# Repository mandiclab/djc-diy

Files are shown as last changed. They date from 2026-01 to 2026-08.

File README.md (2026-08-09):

# *DJC-DIY - The World's First DIY DJ Controller*
DJC-DIY is an open-source DJ controller that you can make at home without special tools, skill or knowledge.  
It works with [Mixxx](https://mixxx.org/) (open-source DJ software).  

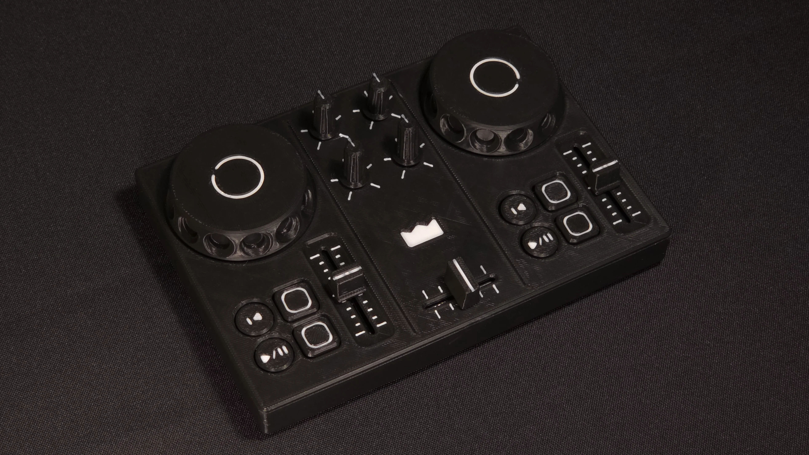
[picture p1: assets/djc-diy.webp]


## ▶️ Videos
👀 **[Preview](https://youtu.be/gbPC8Bg0U9I?si=byUlCWdjjWGdwAEo)**  
🎧 **[Demo](https://youtu.be/WDb8kAIuzXc)**  
🎓 **[Assemby Tutorial](https://youtu.be/Z4C7toXesU8?si=7H11E58jwsbux4Dv)**  
🎓 **[DJ Tutorial - *coming soon*]()**  

## 👥 Community
☕ Support by donating on **[Ko-fi](https://ko-fi.com/mandiclab)**.  
🚀 Join the community on **[Discord](https://discord.gg/aApBQxZUcu)**.  
📱 Subscribe on  **[YouTube](https://youtube.com/@mandiclab)** and follow on **[Instagram](https://instagram.com/mandiclab)**.

## 📁 Project Files

🧊 **3D Models** - *.stl (mesh files for 3D printing), .FCStd (FreeCad source files)*  
⚙️ **Firmware** - *here's the firmware*  
🎛️ **Mixxx Mapping Files** - *and here are the mapping files*

## ⬇️ Download

Download latest stable release from **[releases](https://github.com/mandiclab/djc-diy/releases)**. 

>[!WARNING]
>*If you download the whole repo, there's a chance that you'll download files in the middle of the update process and get incomplete version.*

## 🔩 Parts List

### 3D Printed Parts
| **🔢 Quantity** | **🧊 Part** | **📄 File Name** |
|:---:|:---|:---|
| x1 | Case | case.stl |
| x1 | Front Panel | front-panel.stl |
| x1 | Arduino Spring | arduino-spring.stl |
| x2 | Jog Wheel | jog-wheel.stl |
| x2 | Play/Pause | play-pause.stl |
| x2 | Cue | cue.stl |
| x4 | Performance Pad | performance-pad.stl |
| x1 | Crossfader | crossfader.stl |
| x2 | Tempo Fader | tempo-fader.stl |
| x4 | Knob | knob.stl |
| x4 | Feet | feet.stl |

### 📦 Order 3D Printed Parts From PCBWay 
Thanks to our sponsor **[PCBWay](https://www.pcbway.com/)**, you can now order all 3D printed parts and have them delivered to your door.  
Not having access to a 3D printer is no longer a problem.  

🛒 **[ORDER ALL 3D PRINTED PARTS](https://www.pcbway.com/rapid-prototyping/manufacture/?type=3&reffercode=Project&projectattid=78823)**  
🔎 **[SEE THE WHOLE PROJECT](https://www.pcbway.com/project/shareproject/DIY_DJ_Controller_DJC_DIY_adac65c3.html)**  

*By ordering through PCBWay, you’re also supporting the project and helping future development.*  

### Electronic Components  
| **🔢 Quantity** | **🧩 Component** | **📄 Description** |
|:---:|:---|:---|
| x1 | 🧠 Microcontroller | Arduino Pro Micro - ATmega32U4 - USB Type C |
| x8 | 🔘 Buttons | B3F-4055 - 12x12x7.3mm |
| x4 | 🎛️ Rotary Potentiometers | R0902N - B103 - 10kΩ - 23mm shaft lenght - D shaft |
| x3 | 🎚️ Slide Potentiometers | 60mm - B103 - 10kΩ - 15mm handle lenght |
| x2 | 🔄 Rotary Encoders | EC11 - 15mm shaft lenght - D shaft - without push button |
| x4 | ➖ Resistor | 1/4W - 10kΩ |
|  | 🔌 Wires | 24 AWG - Red, Black, Blue, Green, Yellow|

## 💻 Required Software
**Download and install required software**  

**Arduino IDE** - *an open-source development environment for programming Arduino boards* - **[DOWNLOAD](https://www.arduino.cc/en/software/)**  
**Mixxx** - *an open source DJ software* - **[DOWNLOAD](https://mixxx.org/download/)** 

## 🛠️ Assembly Guide

### 1. Acquire electronic components  
Acquire all electronic components from the electronic components list.  
I personally bought everything from Aliexpress and had no problems.

### 2. 3D print parts  
3D print all parts from the 3D printed parts list.  
I used max speed, 15% infill, .2mm layer height. Use support where needed.  
If something can't be pulled onto a part, try printing it at 105% scale.  

### 3. Wire electronics in the case  
Here you can see an illustrated schematic.  
Solder everything as shown.  

This is the layout of the electronic components.  
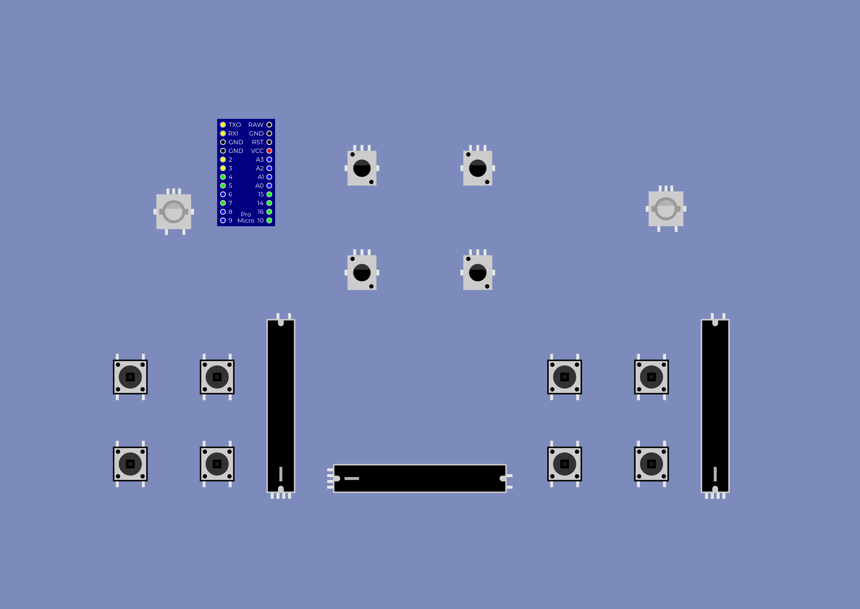
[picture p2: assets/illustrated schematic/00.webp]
  

First solder left rotary encoder.  
At the beginning, solder the pins from the bottom side of the Arduino.  
Use this opportunity to leave more space on the top side for later, because once several electronic components are soldered in place, the Arduino will no longer be movable, and soldering from the bottom side of the pins will no longer be possible.  
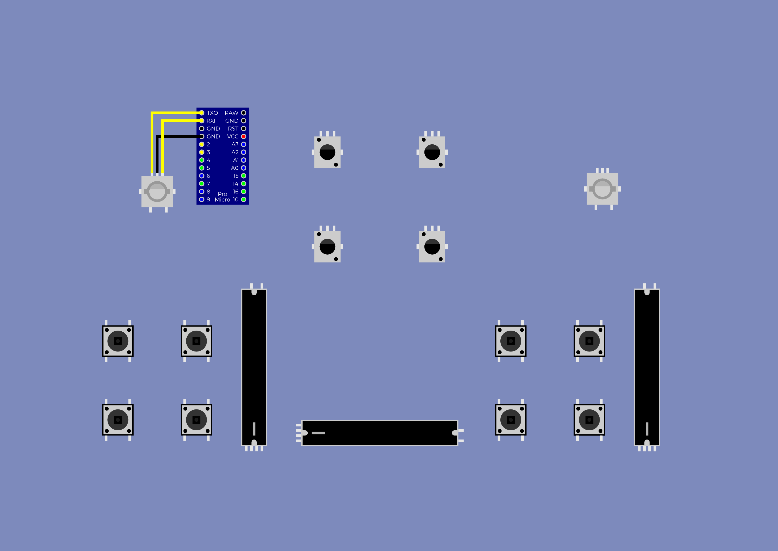
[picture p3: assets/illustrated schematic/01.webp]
  

Then solder right rotary encoder.  
Also solder the pins from the bottom side.  
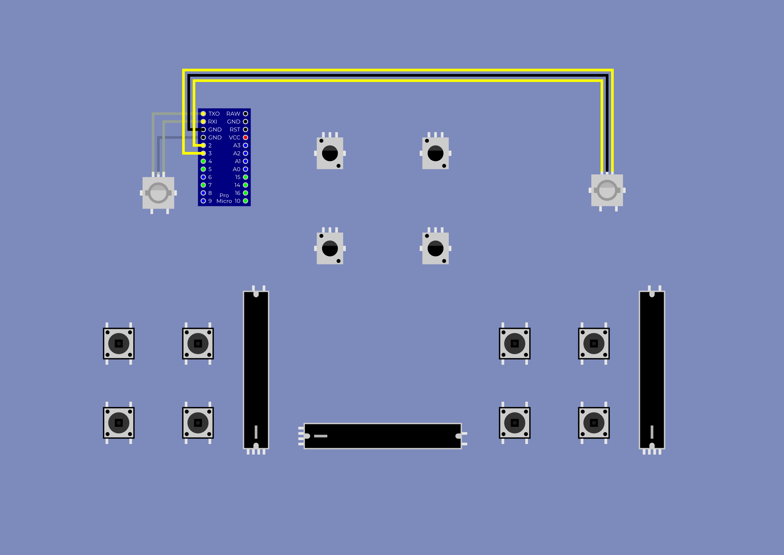
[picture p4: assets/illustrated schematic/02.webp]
  

Next are buttons for the left deck.  
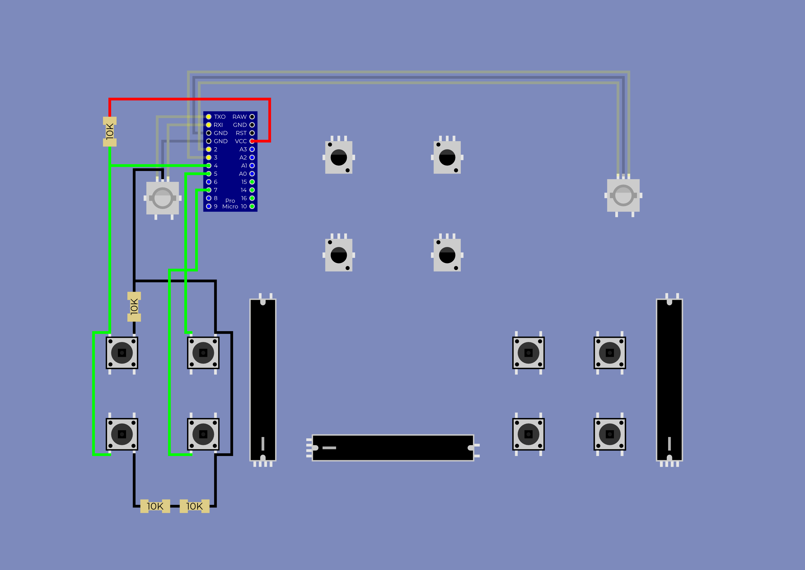
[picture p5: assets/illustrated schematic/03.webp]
  

Then buttons for the right deck.  
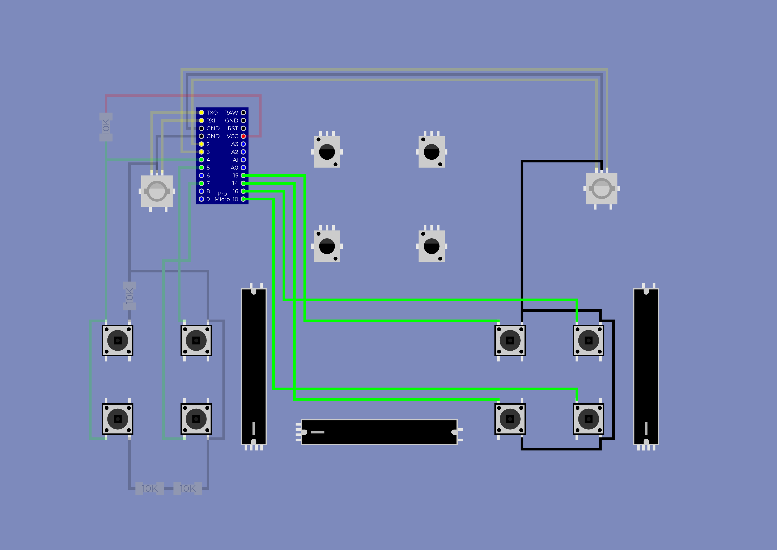
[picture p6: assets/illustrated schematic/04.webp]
  

And the last are potentiometers.
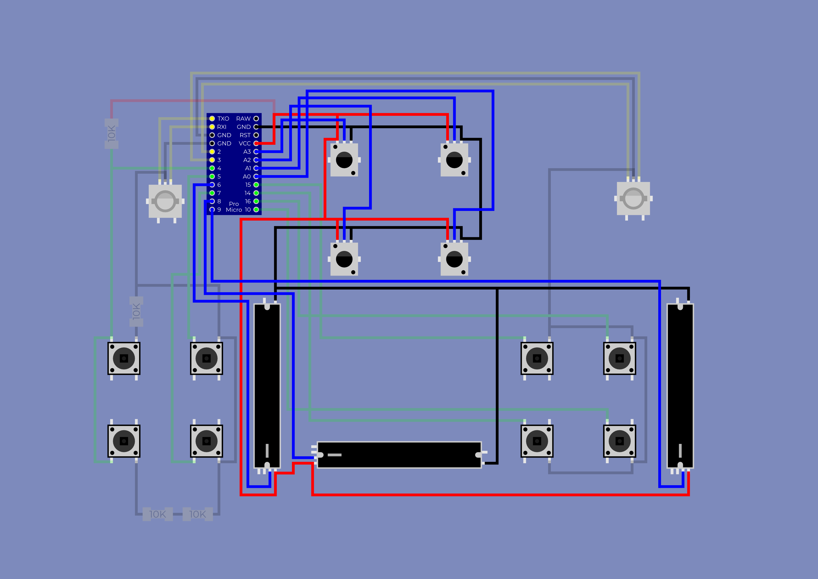
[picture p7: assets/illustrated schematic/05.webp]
  

It should look like this when everything is soldered.
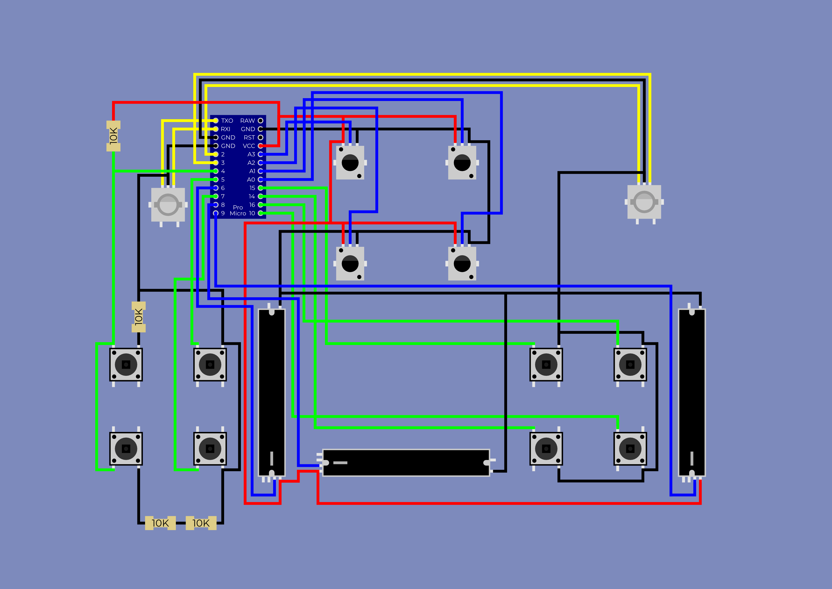
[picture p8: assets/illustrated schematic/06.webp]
  

### 4. Install firmware  
Open firmwar.ino with Arduino IDE.  
Select your board.  
>[!WARNING]
>*If your board is already selected, use it as is. Some arduino clones can only work like that and you can break them otherwise.*

Install MIDIUSB library from Gary Grewal.  
Then upload the code.  

### 5. Install mapping files  
Copy ”DJC-DIY.xml” and ”DJC-DIY-scripts.js” to  
”C:\Users\username\AppData\Local\Mixxx\controllers”.  
Select mapping files by going to the preferences. (Options > Preferences or Ctrl + P)  
Go to the controllers tab and choose something like Arduino/ProMicro/Leonardo.  
Then go to the load mapping and select DJC-DIY.  

### 6. Test the device 
Test your device before assembling rest 3D printed parts.  

### 7. Assemble the rest 3D printed parts  
Assemble the rest 3D printed parts.  
Feel free to use glue where needed.  

## ❓ FAQ

**Q:** Is it for sale?  
**A:** For now, we're not selling the device or DIY kit.

**Q:** Does it work with other DJ software such as Virtual DJ, Rekordbox or Traktor?  
**A:** Currently out of the box it only works with Mixxx, but the controller sends standard MIDI messages, so it can be manually mapped to other software.

## ⚖️ Licenses
**💻 Software** *(.ino, .xml, .js)*  
  Licensed under the [GPL-3.0](LICENSE-SOFTWARE.txt)

**🔩 Hardware** *(.FCStd, .stl)*  
  Licensed under the [CERN-OHL-S-2.0](LICENSE-HARDWARE.txt)

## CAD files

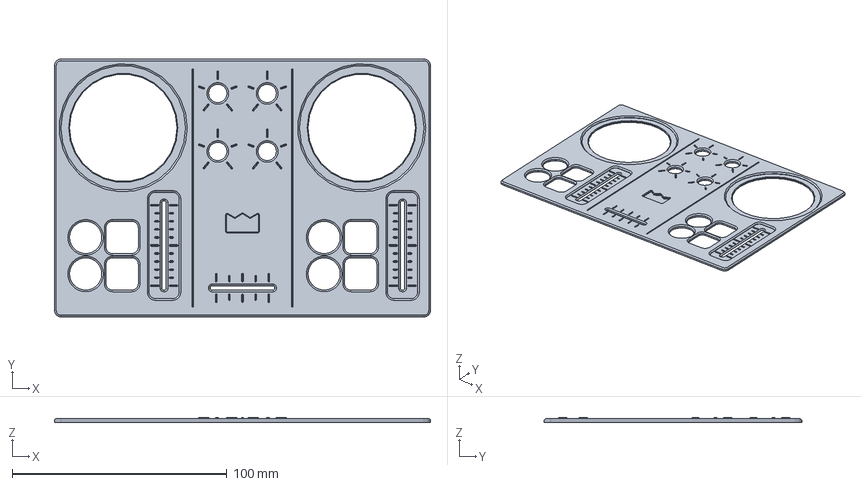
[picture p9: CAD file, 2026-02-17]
3D models/front-panel.FCStd
175.0 x 120.0 x 2.40 mm

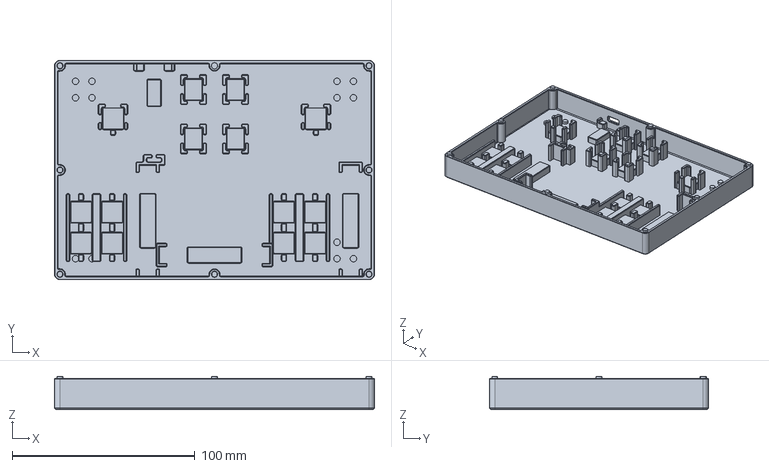
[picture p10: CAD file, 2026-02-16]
3D models/case.FCStd
175.0 x 120.0 x 18.2 mm

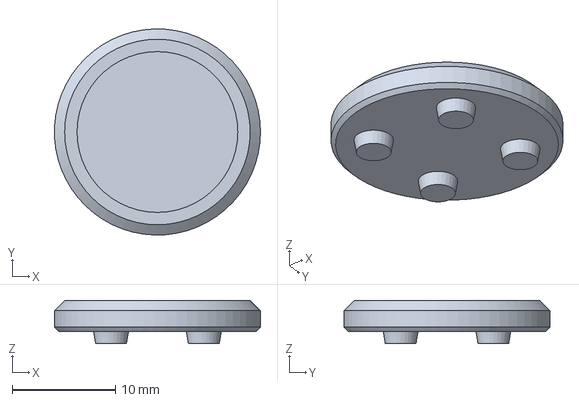
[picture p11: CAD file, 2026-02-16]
3D models/feet.FCStd
20.0 x 20.0 x 4.20 mm

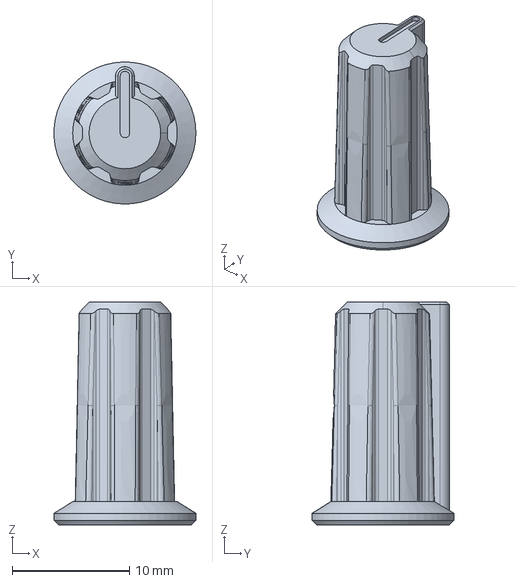
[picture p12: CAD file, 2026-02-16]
3D models/knob.FCStd
12.1 x 12.1 x 19.0 mm

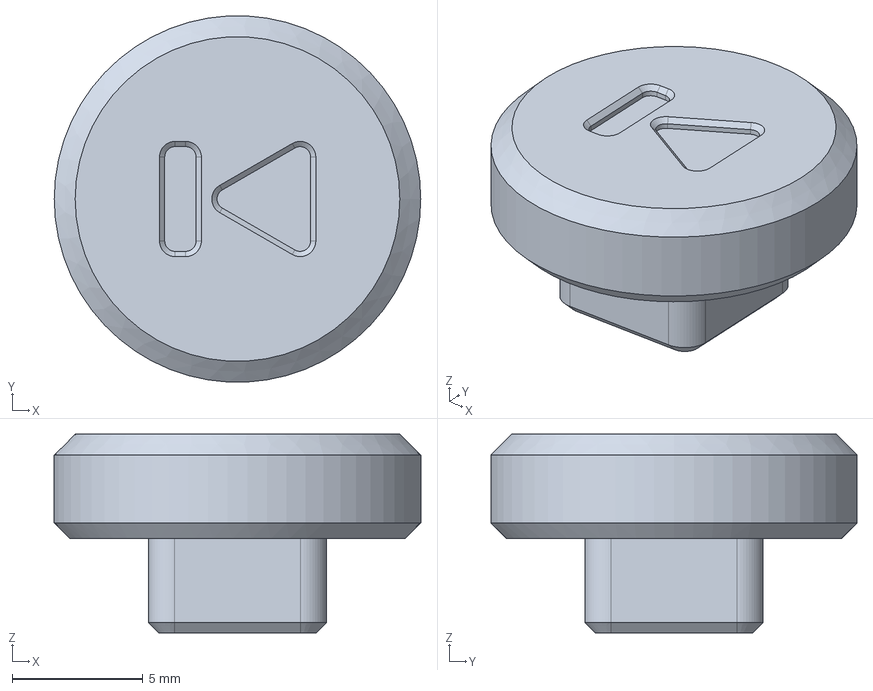
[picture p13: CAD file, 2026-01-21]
3D models/cue.FCStd
14.0 x 14.0 x 7.60 mm

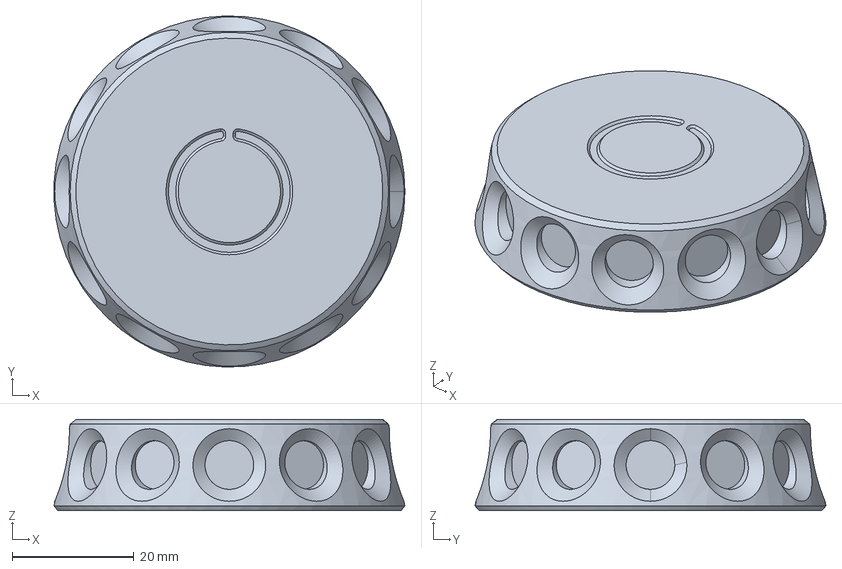
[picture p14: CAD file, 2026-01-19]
3D models/jog-wheel.FCStd
57.6 x 57.7 x 15.0 mm

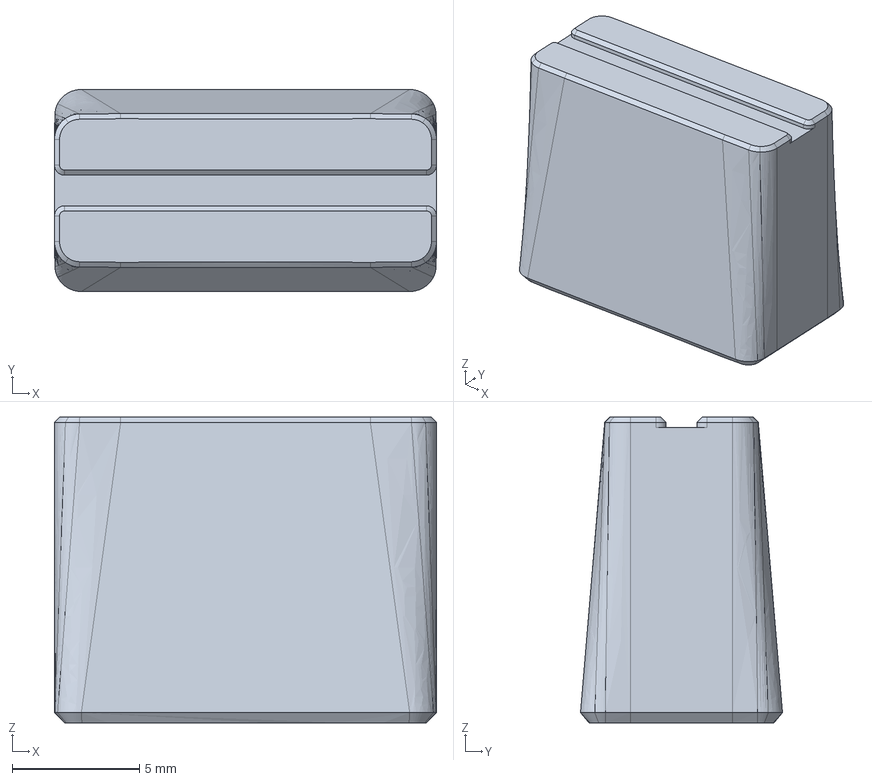
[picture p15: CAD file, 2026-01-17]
3D models/crossfader.FCStd
15.0 x 7.93 x 12.0 mm

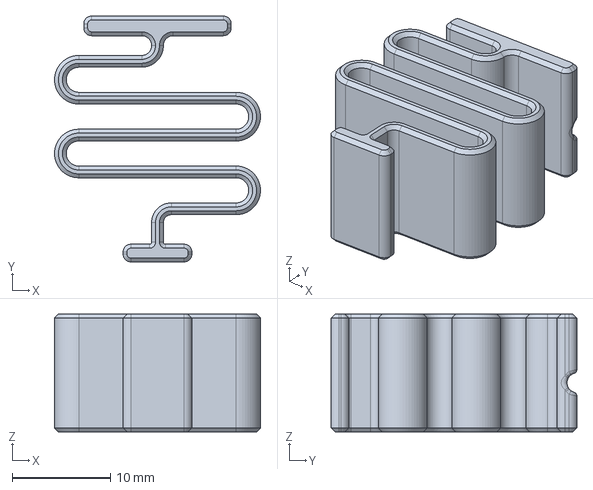
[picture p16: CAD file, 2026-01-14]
3D models/arduino-spring.FCStd
20.9 x 25.0 x 12.0 mm

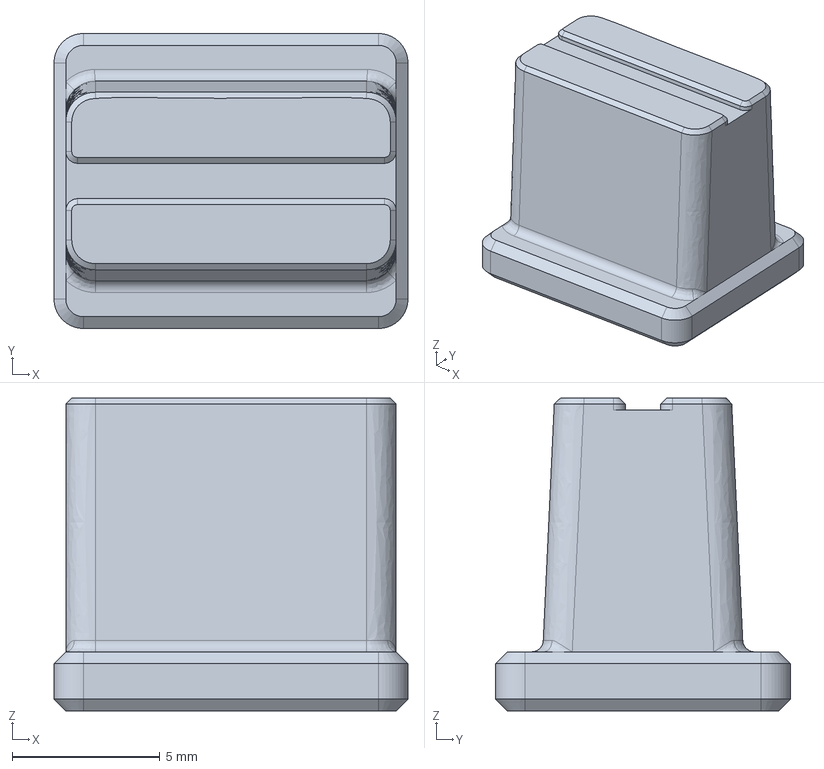
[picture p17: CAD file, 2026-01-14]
3D models/tempo-fader.FCStd
12.0 x 10.0 x 10.6 mm

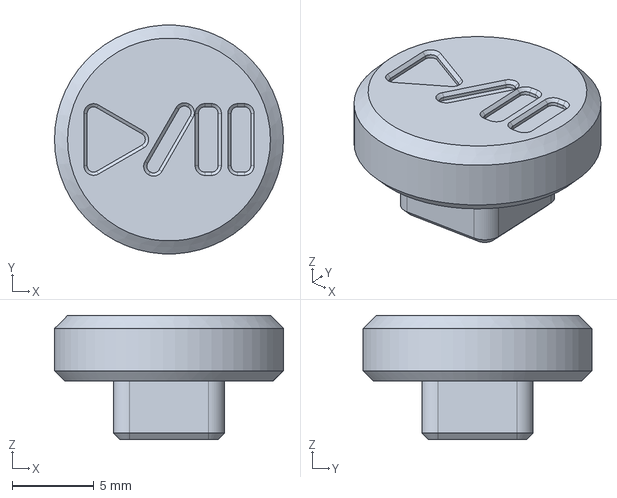
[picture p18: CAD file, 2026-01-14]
3D models/play-pause.FCStd
14.0 x 14.0 x 7.60 mm

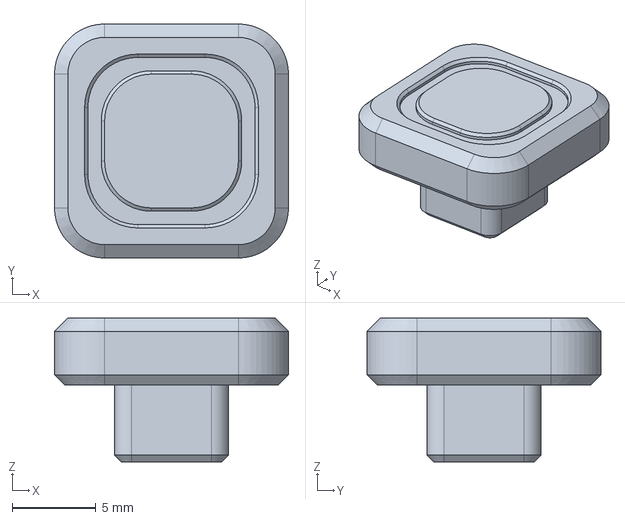
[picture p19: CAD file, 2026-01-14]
3D models/performance-pad.FCStd
14.0 x 14.0 x 8.60 mm

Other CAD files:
assets/all parts plate/all-parts-plate.FCStd
3D models/arduino-spring.stl
3D models/case.stl
3D models/crossfader.stl
3D models/cue.stl
3D models/feet.stl
3D models/front-panel.stl
3D models/jog-wheel.stl
3D models/knob.stl
3D models/performance-pad.stl
3D models/play-pause.stl
3D models/tempo-fader.stl
assets/all parts plate/all-parts-plate.stl

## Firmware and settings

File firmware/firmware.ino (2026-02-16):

#include <MIDIUSB.h>

// ---------- PUSH BUTTONS ----------
const int buttonPins[] = {5, 7, 10, 14, 15, 16};
const byte buttonNotes[] = {60, 61, 62, 63, 64, 65};
bool buttonStates[6] = {0};

// ---------- PUSH BUTTONS ON ANALOG PIN (resistor ladder 10k/10k/20k) ----------
const byte NOTE_1 = 66;
const byte NOTE_2 = 67;

bool note1On = false;
bool note2On = false;

// ADC reference zones
const int BTN1_MIN = 450;  // ~512
const int BTN1_MAX = 580;

const int BTN2_MIN = 630;  // ~680
const int BTN2_MAX = 750;


// ---------- POTENTIOMETERS ----------
const int potPins[] = {A0, A1, A2, A3, A7, A8, A9};
const byte potCCs[] = {10, 11, 12, 13, 14, 15, 16};
int potValues[7] = {0};
const int potThreshold = 2;

// ---------- POT CALIBRATION (centered span) ----------
const int ADC_MID = 512;     // middle of 10-bit ADC
const int SPAN_A7_A9 = 900;  // measured travel
const int SPAN_A8    = 600;  // measured travel

const int A7_MIN = ADC_MID - (SPAN_A7_A9 / 2);
const int A7_MAX = ADC_MID + (SPAN_A7_A9 / 2);
const int A8_MIN = ADC_MID - (SPAN_A8    / 2);
const int A8_MAX = ADC_MID + (SPAN_A8    / 2);
const int A9_MIN = ADC_MID - (SPAN_A7_A9 / 2);
const int A9_MAX = ADC_MID + (SPAN_A7_A9 / 2);

// ---------- ROTARY ENCODERS ----------
const int encoderAPins[] = {0, 3};
const int encoderBPins[] = {1, 2};
const byte encoderCCs[] = {20, 21};

int encoderLastStates[] = {0, 0};

void setup() {
  for (int i = 0; i < 6; i++) {
    pinMode(buttonPins[i], INPUT_PULLUP);
  }

  for (int i = 0; i < 2; i++) {
    pinMode(encoderAPins[i], INPUT_PULLUP);
    pinMode(encoderBPins[i], INPUT_PULLUP);
    encoderLastStates[i] = digitalRead(encoderAPins[i]);
  }
}

void loop() {
  // ------------------ PUSH BUTTONS ------------------
  for (int i = 0; i < 6; i++) {
    bool pressed = !digitalRead(buttonPins[i]);

    if (pressed && !buttonStates[i]) {
      noteOn(buttonNotes[i]);
      buttonStates[i] = true;
    } else if (!pressed && buttonStates[i]) {
      noteOff(buttonNotes[i]);
      buttonStates[i] = false;
    }
  }

// ------------------ PUSH BUTTONS ON ANALOG PIN ------------------
int val = analogRead(A6);

// Button 1 (10k to GND)
if (val > BTN1_MIN && val < BTN1_MAX) {
  if (!note1On) {
    noteOn(NOTE_1);
    note1On = true;
  }
} else {
  if (note1On) {
    noteOff(NOTE_1);
    note1On = false;
  }
}

// Button 2 (10k + 10k to GND)
if (val > BTN2_MIN && val < BTN2_MAX) {
  if (!note2On) {
    noteOn(NOTE_2);
    note2On = true;
  }
} else {
  if (note2On) {
    noteOff(NOTE_2);
    note2On = false;
  }
}

  handlePots();
  handleEncoders();

  delay(5); // debounce
}

// ------------------ MIDI FUNCTIONS ------------------

void noteOn(byte pitch) {
  midiEventPacket_t noteOnMsg = {0x09, 0x90, pitch, 127};
  MidiUSB.sendMIDI(noteOnMsg);
  MidiUSB.flush();
}

void noteOff(byte pitch) {
  midiEventPacket_t noteOffMsg = {0x08, 0x80, pitch, 0};
  MidiUSB.sendMIDI(noteOffMsg);
  MidiUSB.flush();
}

void handlePots() {
  static unsigned long lastReadTime = 0;
  const unsigned long readInterval = 10;

  if (millis() - lastReadTime < readInterval) return;
  lastReadTime = millis();

  for (int i = 0; i < 7; i++) {
    int raw = analogRead(potPins[i]);

    // ------------------ POT CALIBRATION (A7/A8/A9) ------------------
    if (i == 4) raw = constrain(raw, A7_MIN, A7_MAX); // A7 centered span
    if (i == 5) raw = constrain(raw, A8_MIN, A8_MAX); // A8 centered span
    if (i == 6) raw = constrain(raw, A9_MIN, A9_MAX); // A9 centered span

    int mapped;
    if (i == 4) mapped = map(raw, A7_MIN, A7_MAX, 0, 127);
    else if (i == 5) mapped = map(raw, A8_MIN, A8_MAX, 0, 127);
    else if (i == 6) mapped = map(raw, A9_MIN, A9_MAX, 0, 127);
    else mapped = raw / 8; // default: 0-1023 -> 0-127

    if (abs(mapped - potValues[i]) >= potThreshold) {
      potValues[i] = mapped;
      sendCC(potCCs[i], mapped);
    }
  }
}

void sendCC(byte cc, byte val) {
  midiEventPacket_t ccMsg = {0x0B, 0xB0, cc, val};
  MidiUSB.sendMIDI(ccMsg);
  MidiUSB.flush();
}

void handleEncoders() {
  for (int i = 0; i < 2; i++) {
    int currentState = digitalRead(encoderAPins[i]);

    if (currentState != encoderLastStates[i]) {
      int bState = digitalRead(encoderBPins[i]);
      byte directionValue;

      if (currentState == bState) {
        directionValue = 0x41;
      } else {
        directionValue = 0x3F;
      }

      midiEventPacket_t cc = {0x0B, 0xB0, encoderCCs[i], directionValue};
      MidiUSB.sendMIDI(cc);
      MidiUSB.flush();

      encoderLastStates[i] = currentState;
    }
  }
}

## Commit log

2025-07-14 fix case
    [body_case.FCStd]
2025-07-29 add assembly guide
    [body_case.FCStd, body_front-panel.FCStd, button_cue.FCStd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]
2026-01-03 remove old 3D models
    [body_case.FCStd, body_front-panel.FCStd, button_cue.FCStd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]
2026-01-03 add new 3D models
    [assembly.FCStd, case.FCStd, cue.FCStd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]
2026-01-03 (front-panel, play-pause, cue) add chamfer
    [assembly.FCStd, cue.FCStd, front-panel.FCStd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]
2026-01-03 (front-panel, play-pause, cue) fix chamfer
    [assembly.FCStd, cue.FCStd, front-panel.FCStd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]
2026-01-03 (front-panel, performance-pad) add chamfer
    [assembly.FCStd, front-panel.FCStd, performance-pad.FCStd]
2026-01-03 (front-panel) remove chamfer
    [front-panel.FCStd]
2026-01-04 (cue, performance-pad, play-pause) fix socket
    [cue.FCStd, performance-pad.FCStd, play-pause.FCStd]
2026-01-04 (case) add feet socket
    [case.FCStd]
2026-01-04 add feet
    [feet.FCStd]
2026-01-04 add crossfader
    [crossfader.FCStd]
2026-01-05 (case) add some sockets
    [case.FCStd]
2026-01-05 (front-panel) indent tempo-fader
    [front-panel.FCStd]
2026-01-05 (front-panel) decrease lenght of crossfader
    [front-panel.FCStd]
2026-01-05 (front-panel) decrease lenght of tempo-fader
    [front-panel.FCStd]
2026-01-05 (play-pause) new marks
    [play-pause.FCStd]
2026-01-05 new marks
    [cue.FCStd]
2026-01-05 (front-panel) move jog wheel holes
    [front-panel.FCStd]
2026-01-06 (front-panel) add tempo-fader and crossfader marks
    [front-panel.FCStd]
2026-01-06 (crossfader) fix hole and dimensions
    [crossfader.FCStd]
2026-01-06 (crossfader) fix dimensions
    [crossfader.FCStd]
2026-01-06 (crossfader) fix attachment face
    [crossfader.FCStd]
2026-01-06 add tempo-fader
    [tempo-fader.FCStd]
2026-01-06 (front-panel) new crossfader marks
    [front-panel.FCStd]
2026-01-06 add knob
    [knob.FCStd]
2026-01-06 (front-panel) fix crossfader marks
    [front-panel.FCStd]
2026-01-07 (front-panel) add knob marks
    [front-panel.FCStd]
2026-01-07 (front-panel) add chamfers
    [front-panel.FCStd]
2026-01-07 (front-panel) add fillets
    [front-panel.FCStd]
2026-01-07 (front-panel) add logo
    [front-panel.FCStd]
2026-01-07 (front-panel) update chamfer
    [front-panel.FCStd]
2026-01-07 (case) add sockets
    [case.FCStd]
2026-01-07 (case) add fillets and update snap-fit system
    [case.FCStd]
2026-01-07 (front-panel) add separation lines and move back jog-wheel
    [front-panel.FCStd]
2026-01-07 (case) move back jog-wheel
    [case.FCStd]
2026-01-08 (case) add chamfer
    [case.FCStd]
2026-01-08 (case) remove fillets that bocks slider pots
    [case.FCStd]
2026-01-08 (crossfader, knob, tempo-fader) add chamfer
    [crossfader.FCStd, knob.FCStd, tempo-fader.FCStd]
2026-01-08 (performance-pad, play-pause) increase face thickness, shorten socket hole
    [performance-pad.FCStd, play-pause.FCStd]
2026-01-08 (crossfader, cue, knob, performance-pad, play-pause, tempo-fader) add chamfer
    [crossfader.FCStd, cue.FCStd, knob.FCStd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]
2026-01-08 (front-panel) update separation lines
    [front-panel.FCStd]
2026-01-09 (crossfader, knob, tempo-fader) narrow holes
    [crossfader.FCStd, knob.FCStd, tempo-fader.FCStd]
2026-01-09 (knob) decrease height
    [knob.FCStd]
2026-01-09 (knob) add knurled grip
    [knob.FCStd]
2026-01-09 (case) add more studs on snap-fit system
    [case.FCStd]
2026-01-09 (feet) update design
    [feet.FCStd]
2026-01-09 (front-panel) fix knob holes
    [front-panel.FCStd]
2026-01-09 (front-panel) add new holes for new studs for snap-fit system
    [front-panel.FCStd]
2026-01-09 (case) fix fillets and add chamfers
    [case.FCStd]
2026-01-09 (front-panel) add chamfer on logo
    [front-panel.FCStd]
2026-01-09 (front-panel) 3.6mm hole diameter for snap-fit system
    [front-panel.FCStd]
2026-01-09 (feet) new stud layout for snap-fit system
    [feet.FCStd]
2026-01-09 (case) 3.4mm stud diameter for snap-fit system
    [case.FCStd]
2026-01-09 (case) new holes layout for feet snap-fit system
    [case.FCStd]
2026-01-09 (front-panel) fix chamfer on logo
    [front-panel.FCStd]
2026-01-09 (front-panel) more chamfers xd
    [front-panel.FCStd]
2026-01-09 (case) enough chamfers?
    [case.FCStd]
2026-01-09 (cue) fix chamfer
    [cue.FCStd]
2026-01-09 (feet) add chamfer
    [feet.FCStd]
2026-01-09 remove assembly
    [assembly.FCStd]
2026-01-09 (tempo-fader) add chamfer and fillet
    [tempo-fader.FCStd]
2026-01-09 (tempo-fader) fix chamfer
    [tempo-fader.FCStd]
2026-01-09 add .stls
    [case.stl, crossfader.stl, cue.stl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]
2026-01-09 (case, front-panel) fix chamfer
    [case.FCStd, front-panel.FCStd]
2026-01-10 (knob) increase height
    [knob.FCStd, knob.stl]
2026-01-10 add jog-wheel
    [jog-wheel.FCStd, jog-wheel.stl]
2026-01-10 (cue, performance-pad, play-pause) add chamfer
    [cue.FCStd, cue.stl, performance-pad.FCStd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]
2026-01-10 (front-panel) add chamfer to marks
    [front-panel.FCStd]
2026-01-10 (front-panel) decrease hole depth of separation lines
    [front-panel.FCStd]
2026-01-10 (front-panel) update .stl
    [front-panel.stl]
2026-01-10 (front-panel, case) fix chamfer on snap-fit system holes
    [case.FCStd, case.stl, front-panel.FCStd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]
2026-01-11 add backward compatible front panel v1.1.0 to v1.0.0
    [front-panel.FCStd]
2026-01-14 add arduino-spring
    [arduino-spring.FCStd]
2026-01-14 add license in .FCStd
    [case.FCStd, crossfader.FCStd, cue.FCStd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]
2026-01-14 (arduino-spring) fix dimensions
    [arduino-spring.FCStd, arduino-spring.stl]
2026-01-14 (arduino-socket) add license
    [arduino-spring.FCStd]
2026-01-17 (feet) fix stud position
    [feet.FCStd, feet.stl]
2026-01-17 (crossfader) fix hole
    [crossfader.FCStd, crossfader.stl]
2026-01-19 (jog-wheel) fix socket hole
    [jog-wheel.FCStd, jog-wheel.stl]
2026-01-21 (cue) fix thickness
    [cue.FCStd, cue.stl]
2026-01-22 (readme) add electronic components list
    Added a parts list section with details on 3D printed parts and electronic components.
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2026-02-16 (backward compatible) add firmware
    [front-panel.FCStd]
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2026-02-16 (case) loose slider pot sockets, snapfit update, (feet) snapfit update, (knob) loose socket
    [case.FCStd, case.stl, feet.FCStd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]
2026-02-17 (front-panel) improve snap-fit system
    [front-panel.FCStd, front-panel.stl]
2026-02-21 remove backward compatibility
    [front-panel.FCStd]
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2026-03-10 add all parts plate
    [all-parts-plate.FCStd, all-parts-plate.stl]
2026-03-10 rename all parts plate folder
    [all-parts-plate.FCStd, all-parts-plate.stl]
2026-03-10 repair all-parts-plate.stl and case.stl
    [all-parts-plate.stl, case.stl]
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
